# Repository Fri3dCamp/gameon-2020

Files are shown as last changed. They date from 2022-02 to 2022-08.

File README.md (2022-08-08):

# Fri3d GameOn 2020

This repository contains the hardware design of the [Fri3d Camp](https://fri3d.be/) GameOn that connects to the [badge](https://github.com/Fri3dCamp/badge-2020).
The board consists our of a joystick, some buttons, a Micro SD card slot and a small 1W audio amplifier.
The project progress can be followed on our [Hackaday.io](https://hackaday.io/project/183766-gameon) page.

## Blockdiagram

In order to make the documentation easier to use, we've added the block diagram in this repository.

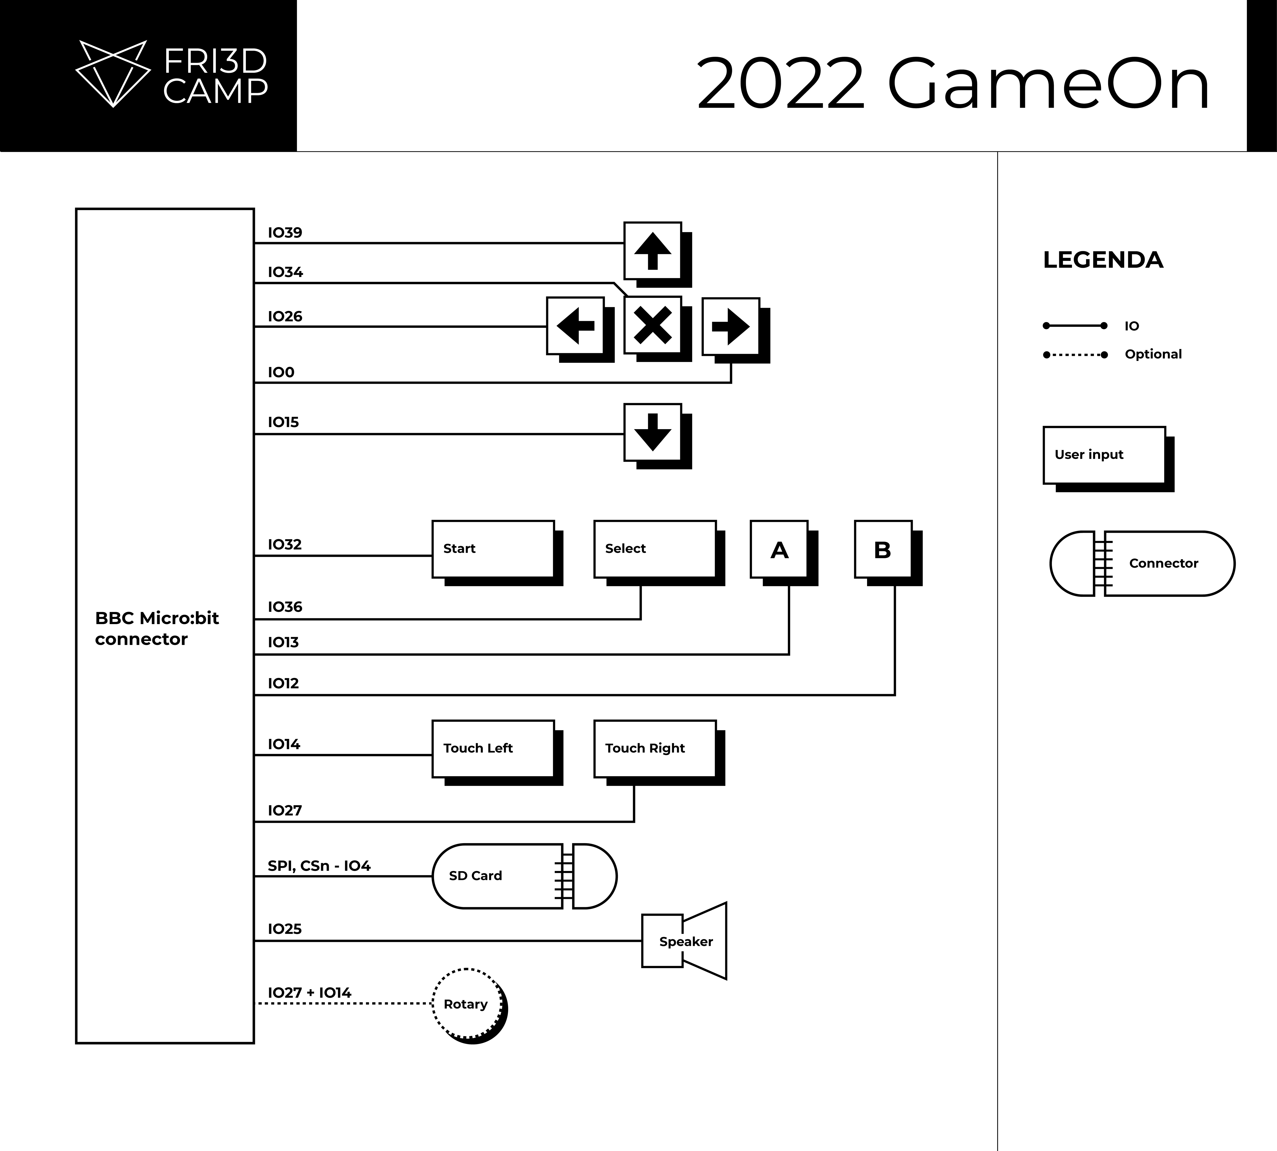
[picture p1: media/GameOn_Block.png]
GameOn Block Diagram


## REV 00
First prototype to verify the schematic design.

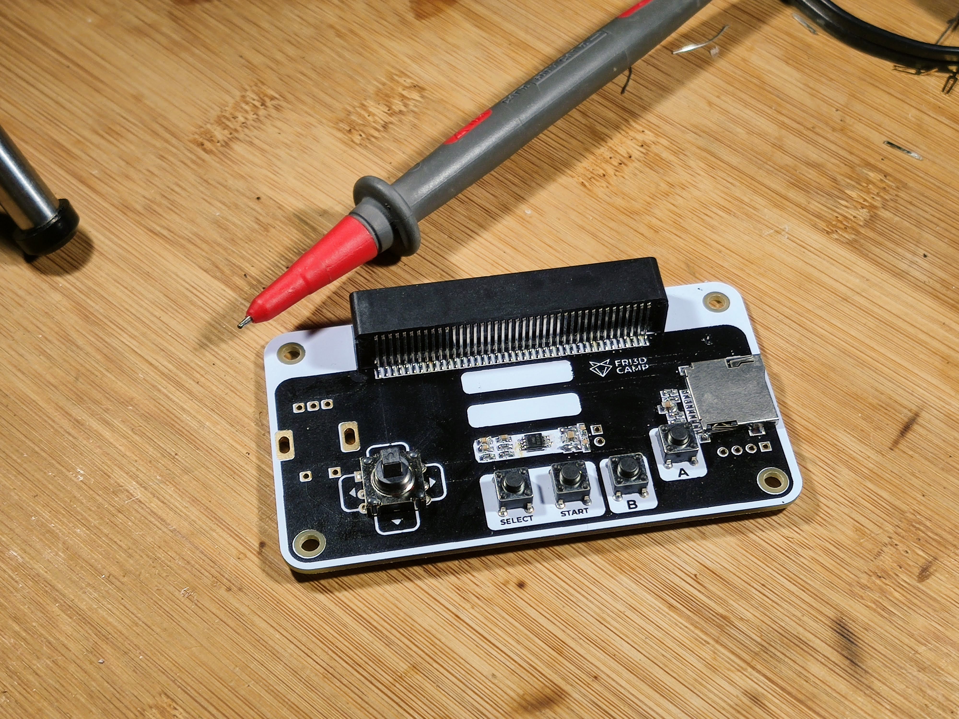
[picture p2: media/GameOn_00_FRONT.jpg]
GameOn Front 00


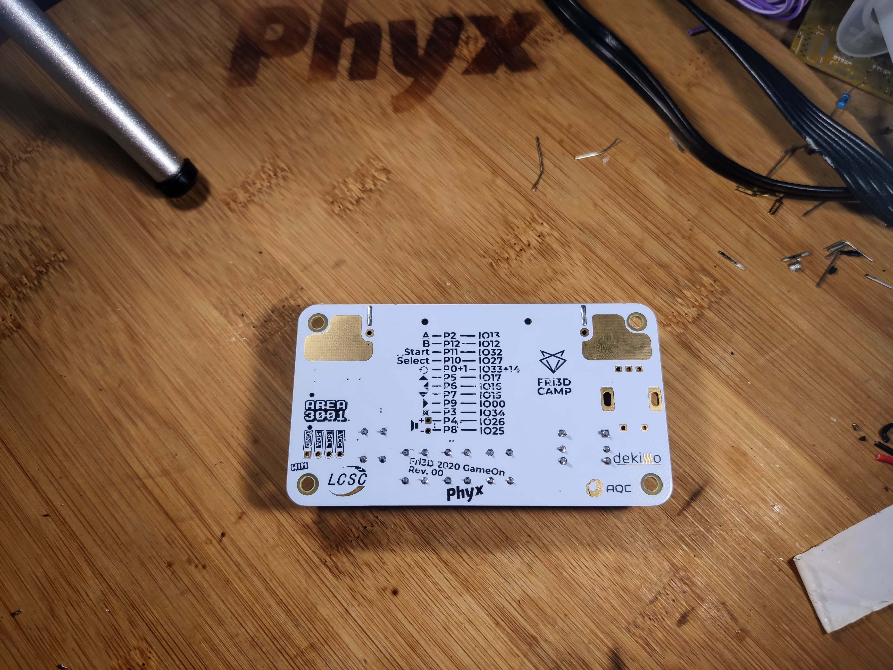
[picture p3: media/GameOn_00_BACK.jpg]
GameOn Back 00


## REV 01
Modified the pinout for the new hardware revision of the badge.

## REV 02
Production version of the GameOn. 

Note that the Start button, connected to the [badge](https://github.com/Fri3dCamp/badge-2020) IO pin 32, is active high whilst all other buttons are active low.

## 3D Printed Joystick
[Mathy Vanvoorden](https://github.com/MathyV)) designed a small joystick to click on the directional switch. Thereby making the directional switch easier to use. You can find the 3D model in the mechanical folder.

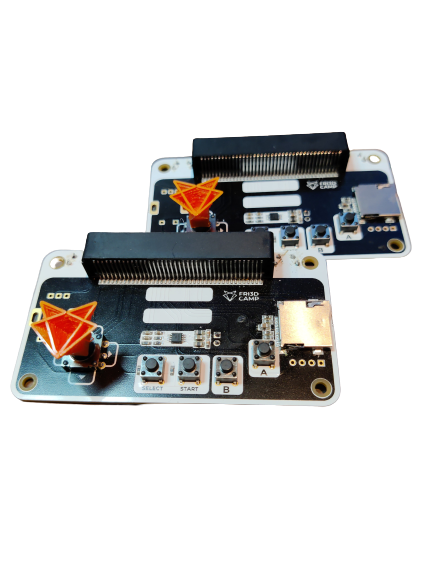
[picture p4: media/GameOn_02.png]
GameOn 02


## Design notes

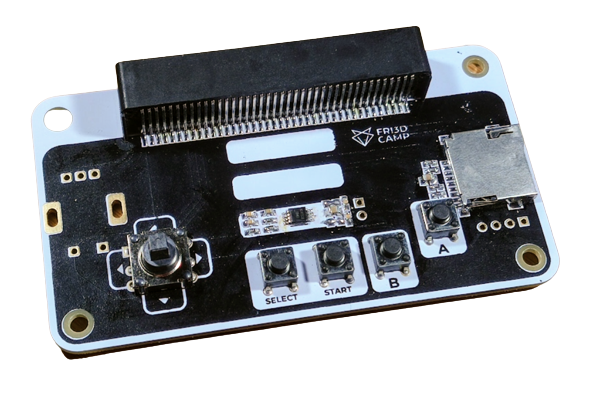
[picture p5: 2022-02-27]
media/GameOn_00_noBG.png

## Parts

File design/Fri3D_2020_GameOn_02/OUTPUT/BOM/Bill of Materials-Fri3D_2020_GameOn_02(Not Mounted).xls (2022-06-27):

Bill of Materials |  |  | Fri3D 2022 GameOn
Project: |  | Fri3D_2020_GameOn_02.PrjPcb
Revision: |  | 02
Variant: |  | Not Mounted
Creation Date: | 06/06/2022 | 20:51
Print Date: | 2022-06-06 | 20:51:31
Footprint | Comment | LibRef | Designator | Value | Description | Supplier 1 | Supplier Part Number 1 | Supplier 2 | Supplier Part Number 2 | Supplier 3 | Supplier Part Number 3 | Quantity
C0603_N |  | CAP # 100nF 50V 0603 | C1, C2 | 100nF 50V | CAP # 100nF 50V 0603 | Farnell | 1759122 | LCSC | C282519 | Generic | 100nF 50V 0603 X7R | 2
C0603_N |  | CAP # 1nF 16V 0603 | C3, C4 | 1nF 16V | CAP # 1nF 16V 0603 |  |  |  |  | Generic | 1nF 16V 0603 X7R | 2
C0805_N |  | CAP # 10uF 10V 0805 | C5, C6 | 10uF 10V | CAP # 10uF 10V 0805 | Farnell | 2320859 | LCSC | C17024 | Generic | 10uF 10V 0805 X7R | 2
C0603_N |  | CAP # 1uF 50V 0603 | C7 | 1uF 50V | CAP # 1uF 50V 0603 | Farnell | 2112858 |  |  | Generic | 1uF 50V 0603 X7R | 1
L0805 |  | FER # 600R 2A 0805 0R10 | F1, F2 | 2A 0R1 | FER # 600R 2A 0805 0R10 | Farnell | 1838838 |  |  |  |  | 2
TFP09-2-12B | Micro SD PiPo Push-Push | MicroSD TFP09-2-12B Push-Push | J1 | TFP09-2-12B | MicroSD TFP09-2-12B Push-Push | AliExpress | TFP09-2-12B | LCSC | C393941 | LCSC | C381082 | 1
MicroBIT_CYLCONN_SMD_180 | MicroBit 180deg connector Cylconn | MicroBit # Cylconn | P2 |  | MicroBit # Cylconn | TaoBao |  |  |  |  |  | 1
R0603_N |  | RES # 10K 0603 | R1, R2, R3, R4, R5, R6, R7, R8, R9 | 10K | RES # 10K 0603 | Farnell | 2502397 | LCSC | C25804 | Generic | 10K 1% 0603 | 9
TACTSW | Default TH TACT | SW TACT | SW1, SW2, SW3, SW4 |  | SW TACT | LCSC | C393938 |  |  |  |  | 4
TACTSW_5W_K1-1506DN-01 | 5Way Tact switch | SW TACT 5W K1-1506DN-01 | SW5 | K1-1506DN-01 | SW TACT 5W K1-1506DN-01 | LCSC | C145911 |  |  |  |  | 1
TACTSW_RA_385 | Tact switch, RA, 3,85mm | SW TACT RA 3,85mm 431256038716 | SW6, SW7 | 431256038716 | SW TACT RA 3,85mm 431256038716 | Wurth | 431256038716 | Mouser | 710-431256038716 |  |  | 2
MAX_uSOP8 | 5W Class D mono amplifier inducter-less Differential input MSOP8 | AMP # AUDIO NS4150B | U1 | NS4150B | AMP # AUDIO NS4150B | LCSC | C189961 |  |  |  |  | 1
 |  |  |  |  |  |  |  |  |  |  |  | 28
Approved |  | Notes

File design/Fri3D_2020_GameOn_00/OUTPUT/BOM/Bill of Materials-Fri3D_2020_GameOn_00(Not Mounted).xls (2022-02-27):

Bill of Materials |  |  | Fri3D 2020 GameOn
Project: |  | Fri3D_2020_GameOn_00.PrjPcb
Revision: |  | 00
Variant: |  | Not Mounted
Creation Date: | 25/03/2020 | 19:29
Print Date: | 2020-03-25 | 19:44:46
Footprint | Comment | LibRef | Designator | Value | Description | Supplier 1 | Supplier PN 1 | Supplier 2 | Supplier PN 2 | Supplier 3 | Supplier PN 3 | Quantity
C0603_N |  | CAP # 100nF 50V 0603 | C1, C2 | 100nF 50V | CAP # 100nF 50V 0603 | LCSC | C83054 | Farnell | 1759122 | Generic | 100nF 50V 0603 X7R | 2
C0603_N |  | CAP # 1nF 16V 0603 | C3, C4 | 1nF 16V | CAP # 1nF 16V 0603 | LCSC | C99917 |  |  | Generic | 1nF 16V 0603 X7R | 2
C0805_N |  | CAP # 10uF 10V 0805 | C5, C6 | 10uF 10V | CAP # 10uF 10V 0805 | LCSC | C1713 | Farnell | 2320859 | Generic | 10uF 10V 0805 X7R | 2
C0603_N |  | CAP # 1uF 50V 0603 | C7 | 1uF 50V | CAP # 1uF 50V 0603 | LCSC | C1592 | Farnell | 2112858 | Generic | 1uF 50V 0603 X7R | 1
L0805 |  | FER # 600R 2A 0805 0R10 | F1, F2 | 2A 0R1 | FER # 600R 2A 0805 0R10 | LCSC | C21286 | Farnell | 1838838 |  |  | 2
TFP09-2-12B | Micro SD PiPo Push-Push | MicroSD TFP09-2-12B Push-Push | J1 | TFP09-2-12B | MicroSD TFP09-2-12B Push-Push | LCSC | C393941 |  |  |  |  | 1
MicroBIT_CYLCONN_SMD_90 | MicroBit 90deg connector Cylconn | MicroBit # RA Cylconn | P1 |  | MicroBit # RA Cylconn | TaoBao |  |  |  |  |  | 1
R0603_N |  | RES # 10K 0603 | R1, R2, R3, R4, R5, R6, R7 | 10K | RES # 10K 0603 | LCSC | C115324 | Farnell | 2502397 | Generic | 10K 1% 0603 | 7
TACTSW | Default TH TACT | SW TACT | SW1, SW2, SW3, SW4 |  | SW TACT | LCSC | C393938 |  |  |  |  | 4
TACTSW_5W_K1-1506DN-01 | 5Way Tact switch | SW TACT 5W K1-1506DN-01 | SW5 | K1-1506DN-01 | SW TACT 5W K1-1506DN-01 | LCSC | C145911 |  |  |  |  | 1
 |  | SPK 8R 1W 23mm | SPEAKER | 23M02-8T-H43 | SPK 8R 1W 23mm | LCSC | C391013 |  |  |  |  | 1
MAX_uSOP8 | 5W Class D mono amplifier inducter-less Differential input MSOP8 | AMP # AUDIO NS4150B | U1 | NS4150B | AMP # AUDIO NS4150B | LCSC | C189961 |  |  |  |  | 1
 |  |  |  |  |  |  |  |  |  |  |  | 25
Approved |  | Notes

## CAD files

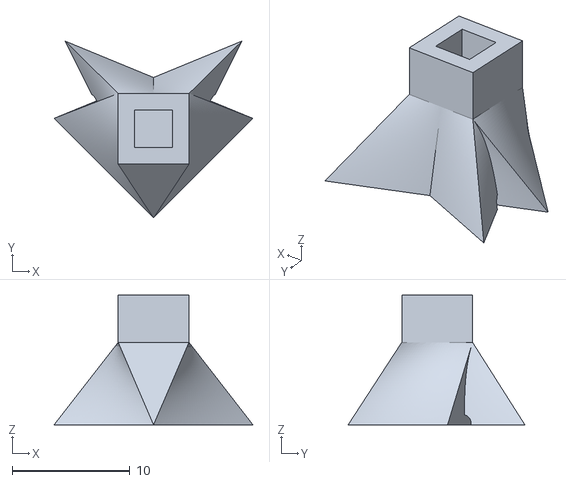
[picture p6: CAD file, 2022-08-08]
mechanical/JoyButton_v3.stl
16.9 x 15.0 x 11.0

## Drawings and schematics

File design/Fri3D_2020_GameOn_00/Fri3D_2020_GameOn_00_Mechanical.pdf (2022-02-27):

## Fri3D 2020 GameOn Mechanical drawings

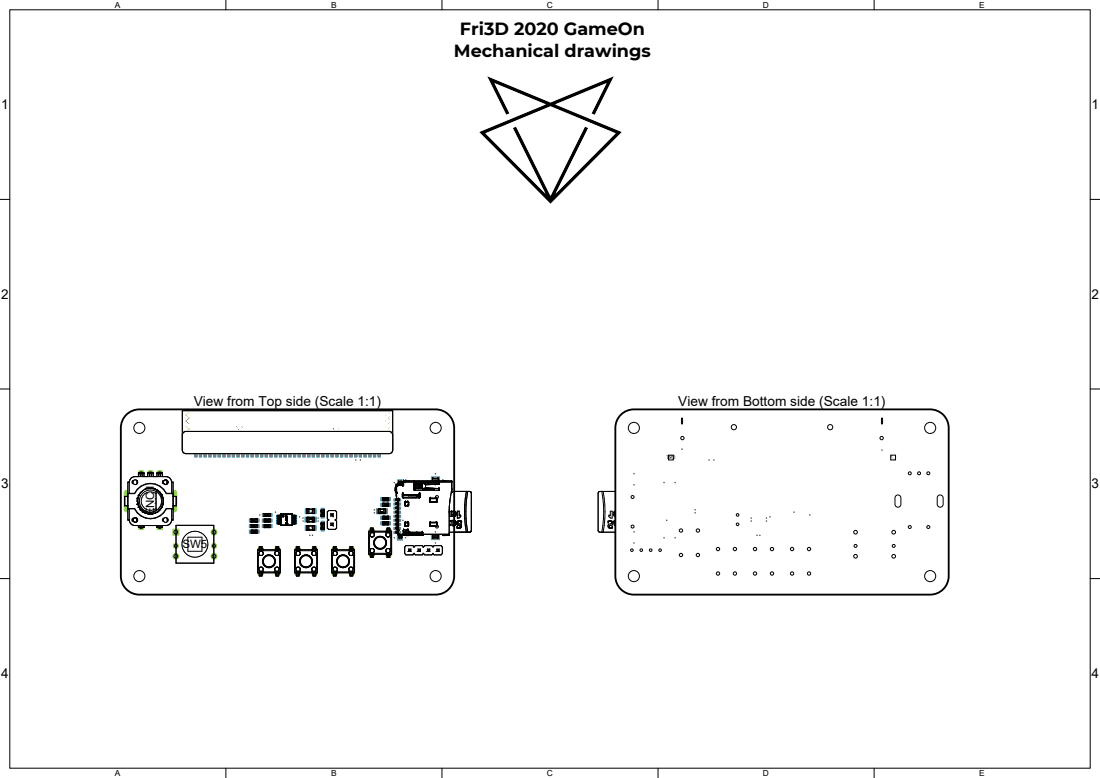
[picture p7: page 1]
4 ENC¹; ENC1

View from Top side (Scale 1:1)

View from Bottom side (Scale 1:1)

## Fri3D 2020 GameOn Silkscreen

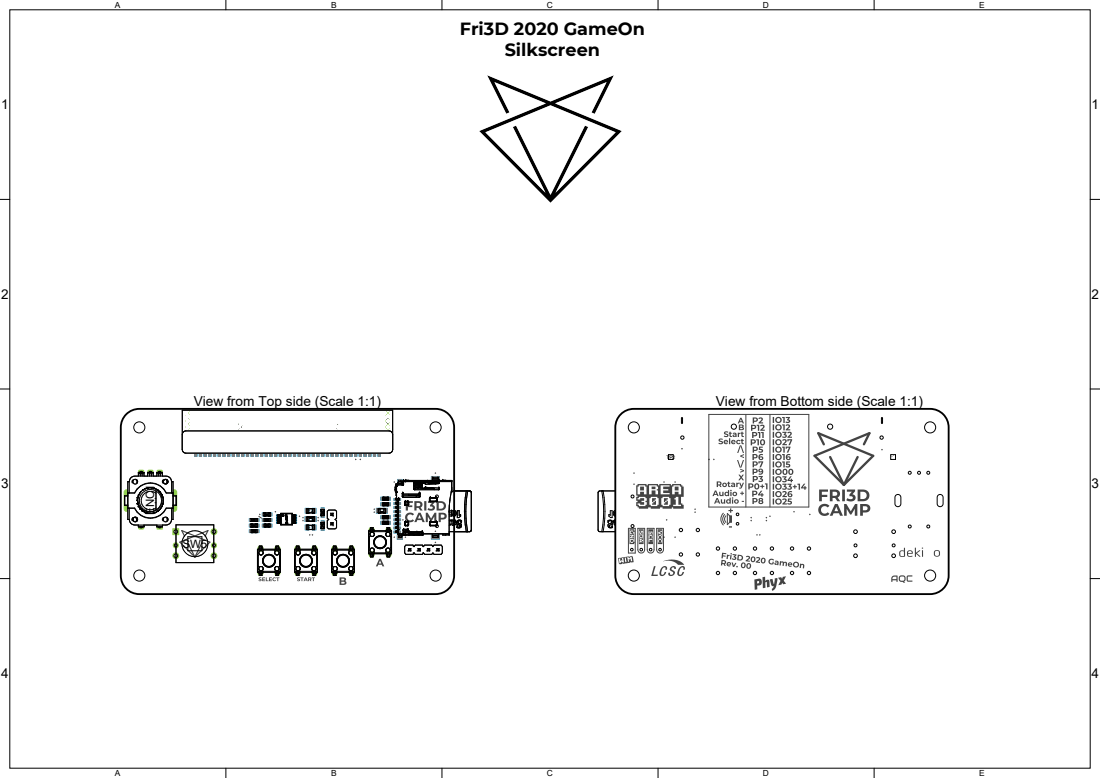
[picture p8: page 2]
ENC1

View from Top side (Scale 1:1)

View from Bottom side (Scale 1:1)

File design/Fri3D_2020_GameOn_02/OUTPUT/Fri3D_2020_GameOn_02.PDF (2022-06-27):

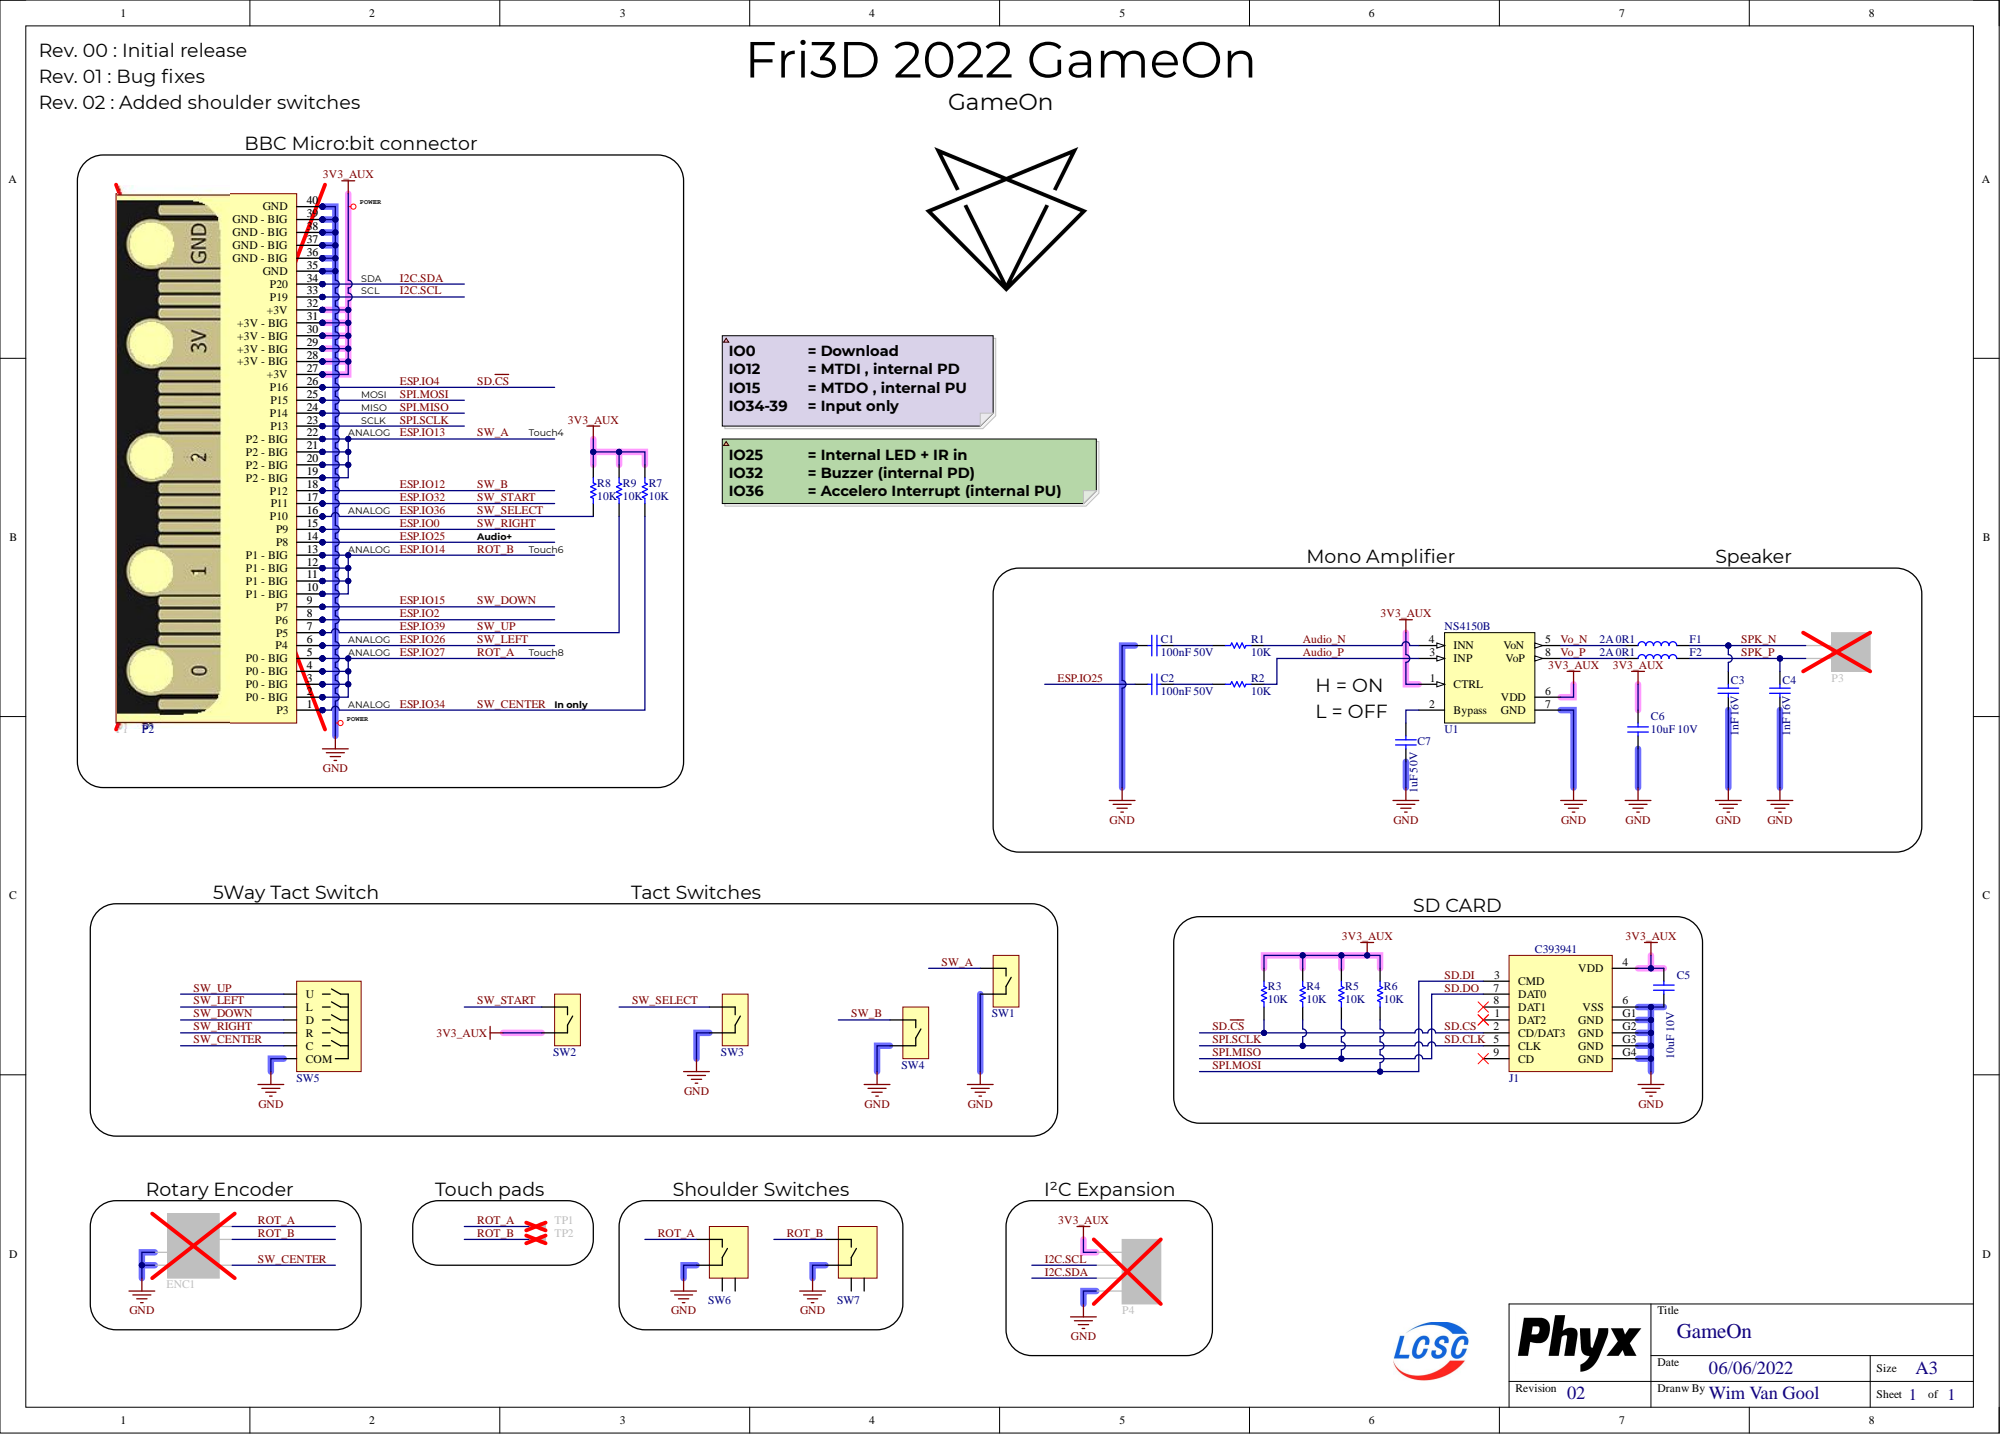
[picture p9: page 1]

Rev. 00 : Initial release
Rev. 01 : Bug fixes
Rev. 02 : Added shoulder switches

BBC Micro:bit connector

SD.CS SD.CLK | DAT1 8

Rev. 00 : Initial release
Rev. 01 : Bug fixes
Rev. 02 : Added shoulder switches

BBC Micro:bit connector

SD.CS SD.CLK | DAT1 8

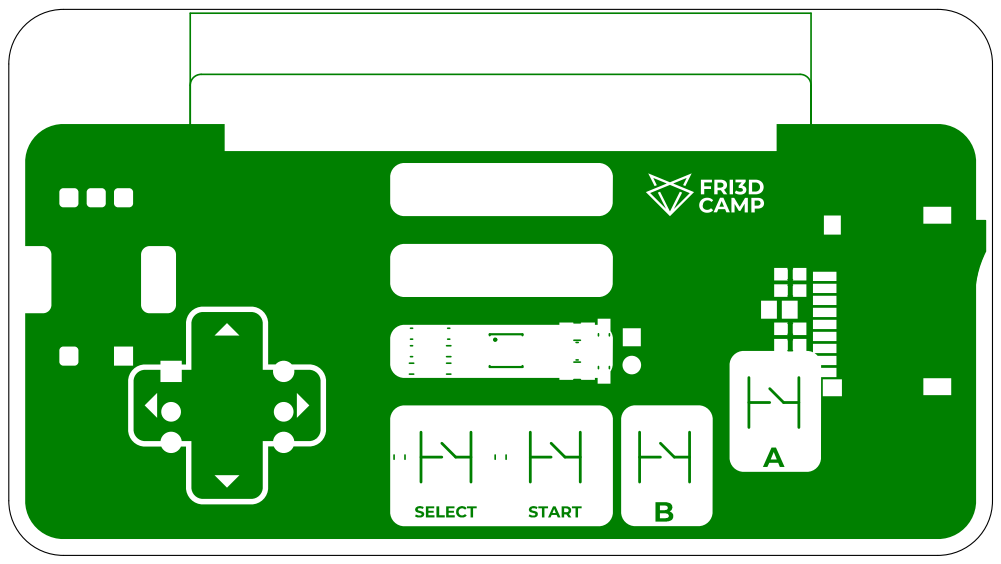
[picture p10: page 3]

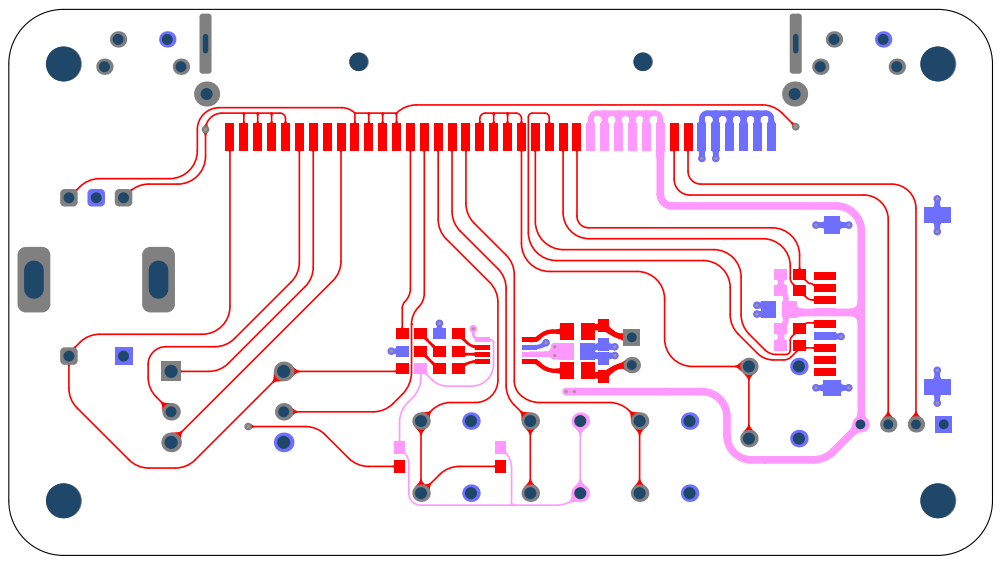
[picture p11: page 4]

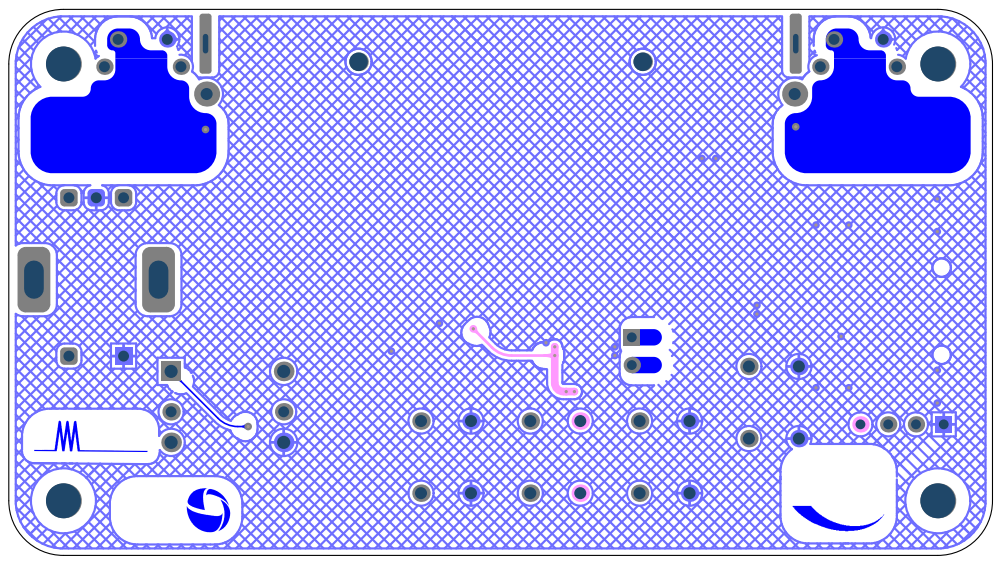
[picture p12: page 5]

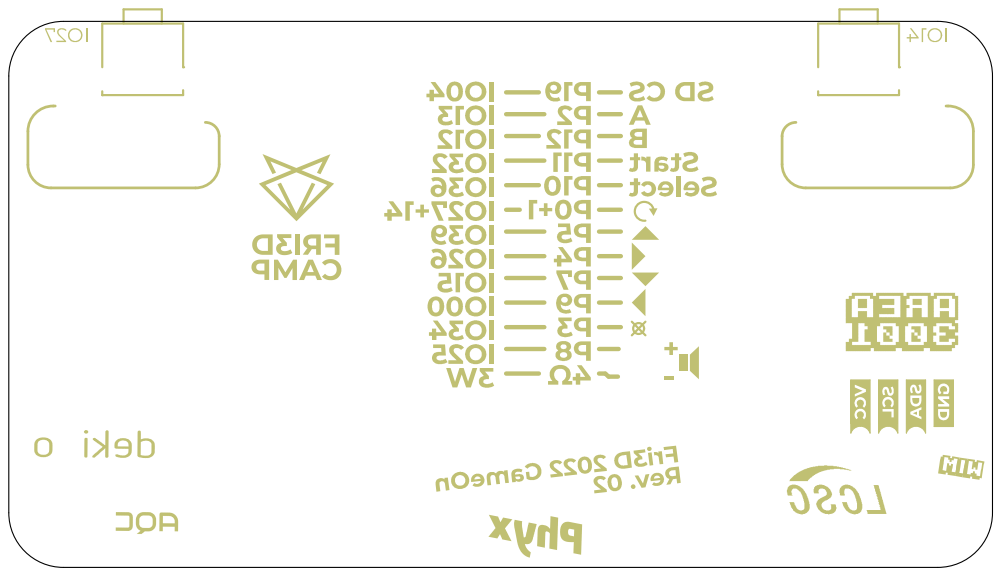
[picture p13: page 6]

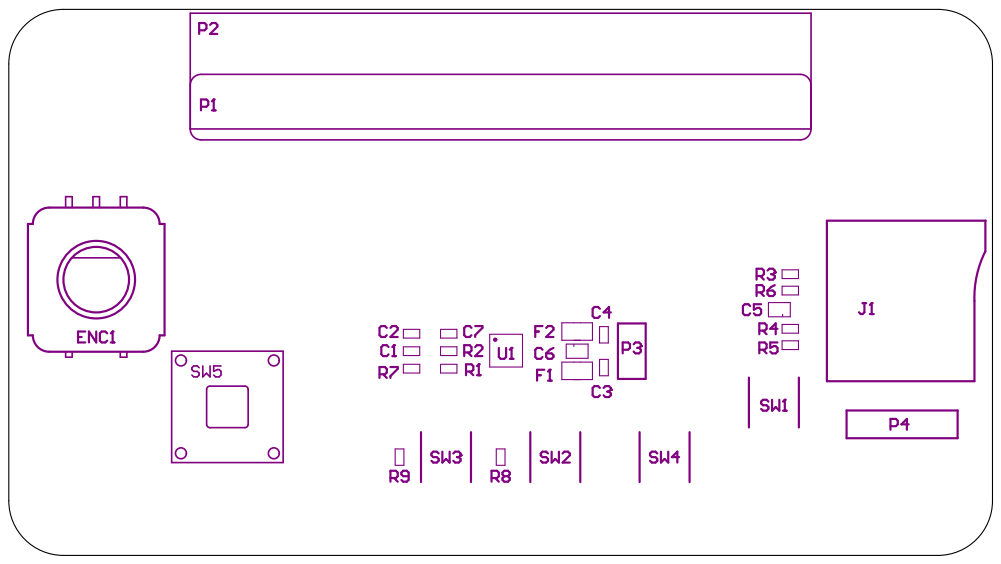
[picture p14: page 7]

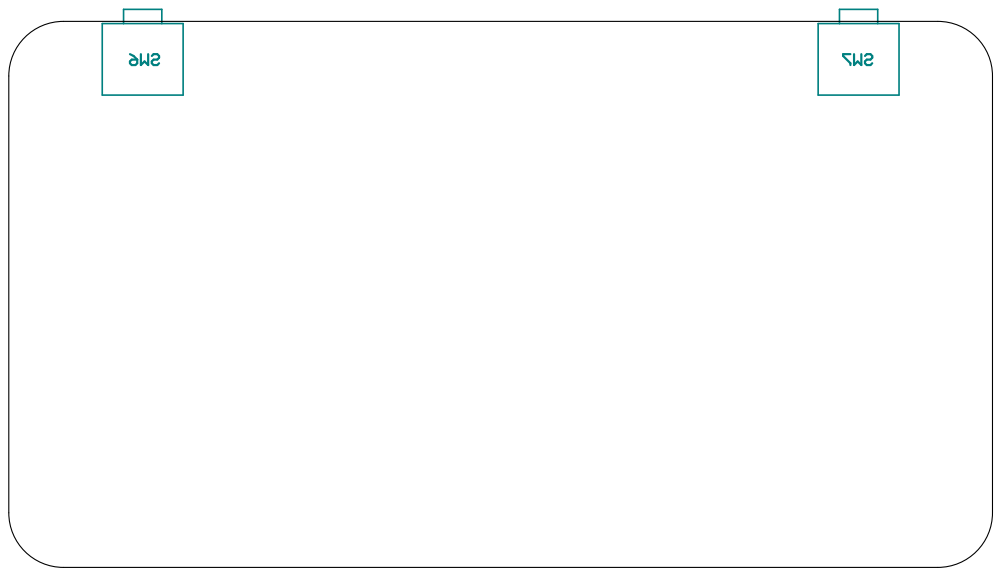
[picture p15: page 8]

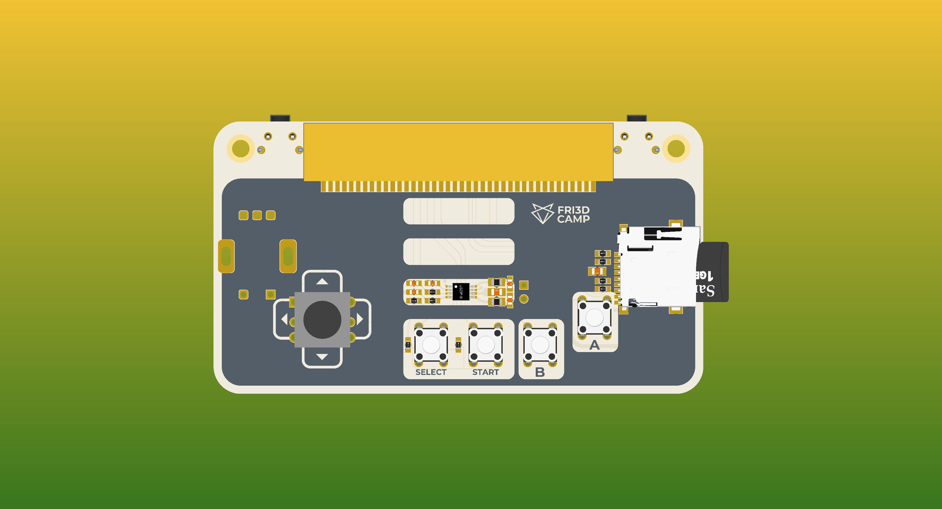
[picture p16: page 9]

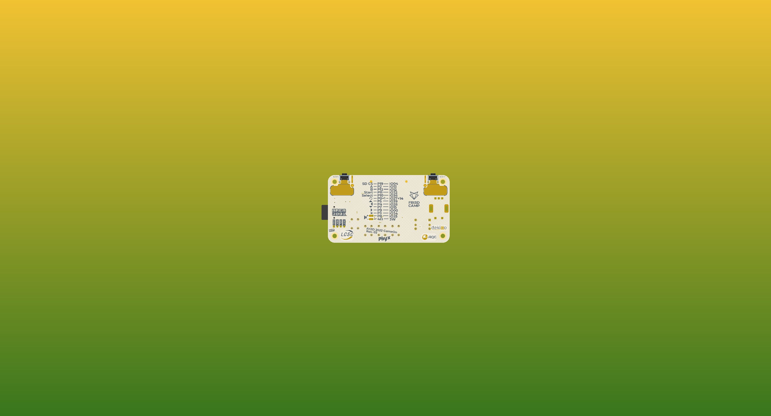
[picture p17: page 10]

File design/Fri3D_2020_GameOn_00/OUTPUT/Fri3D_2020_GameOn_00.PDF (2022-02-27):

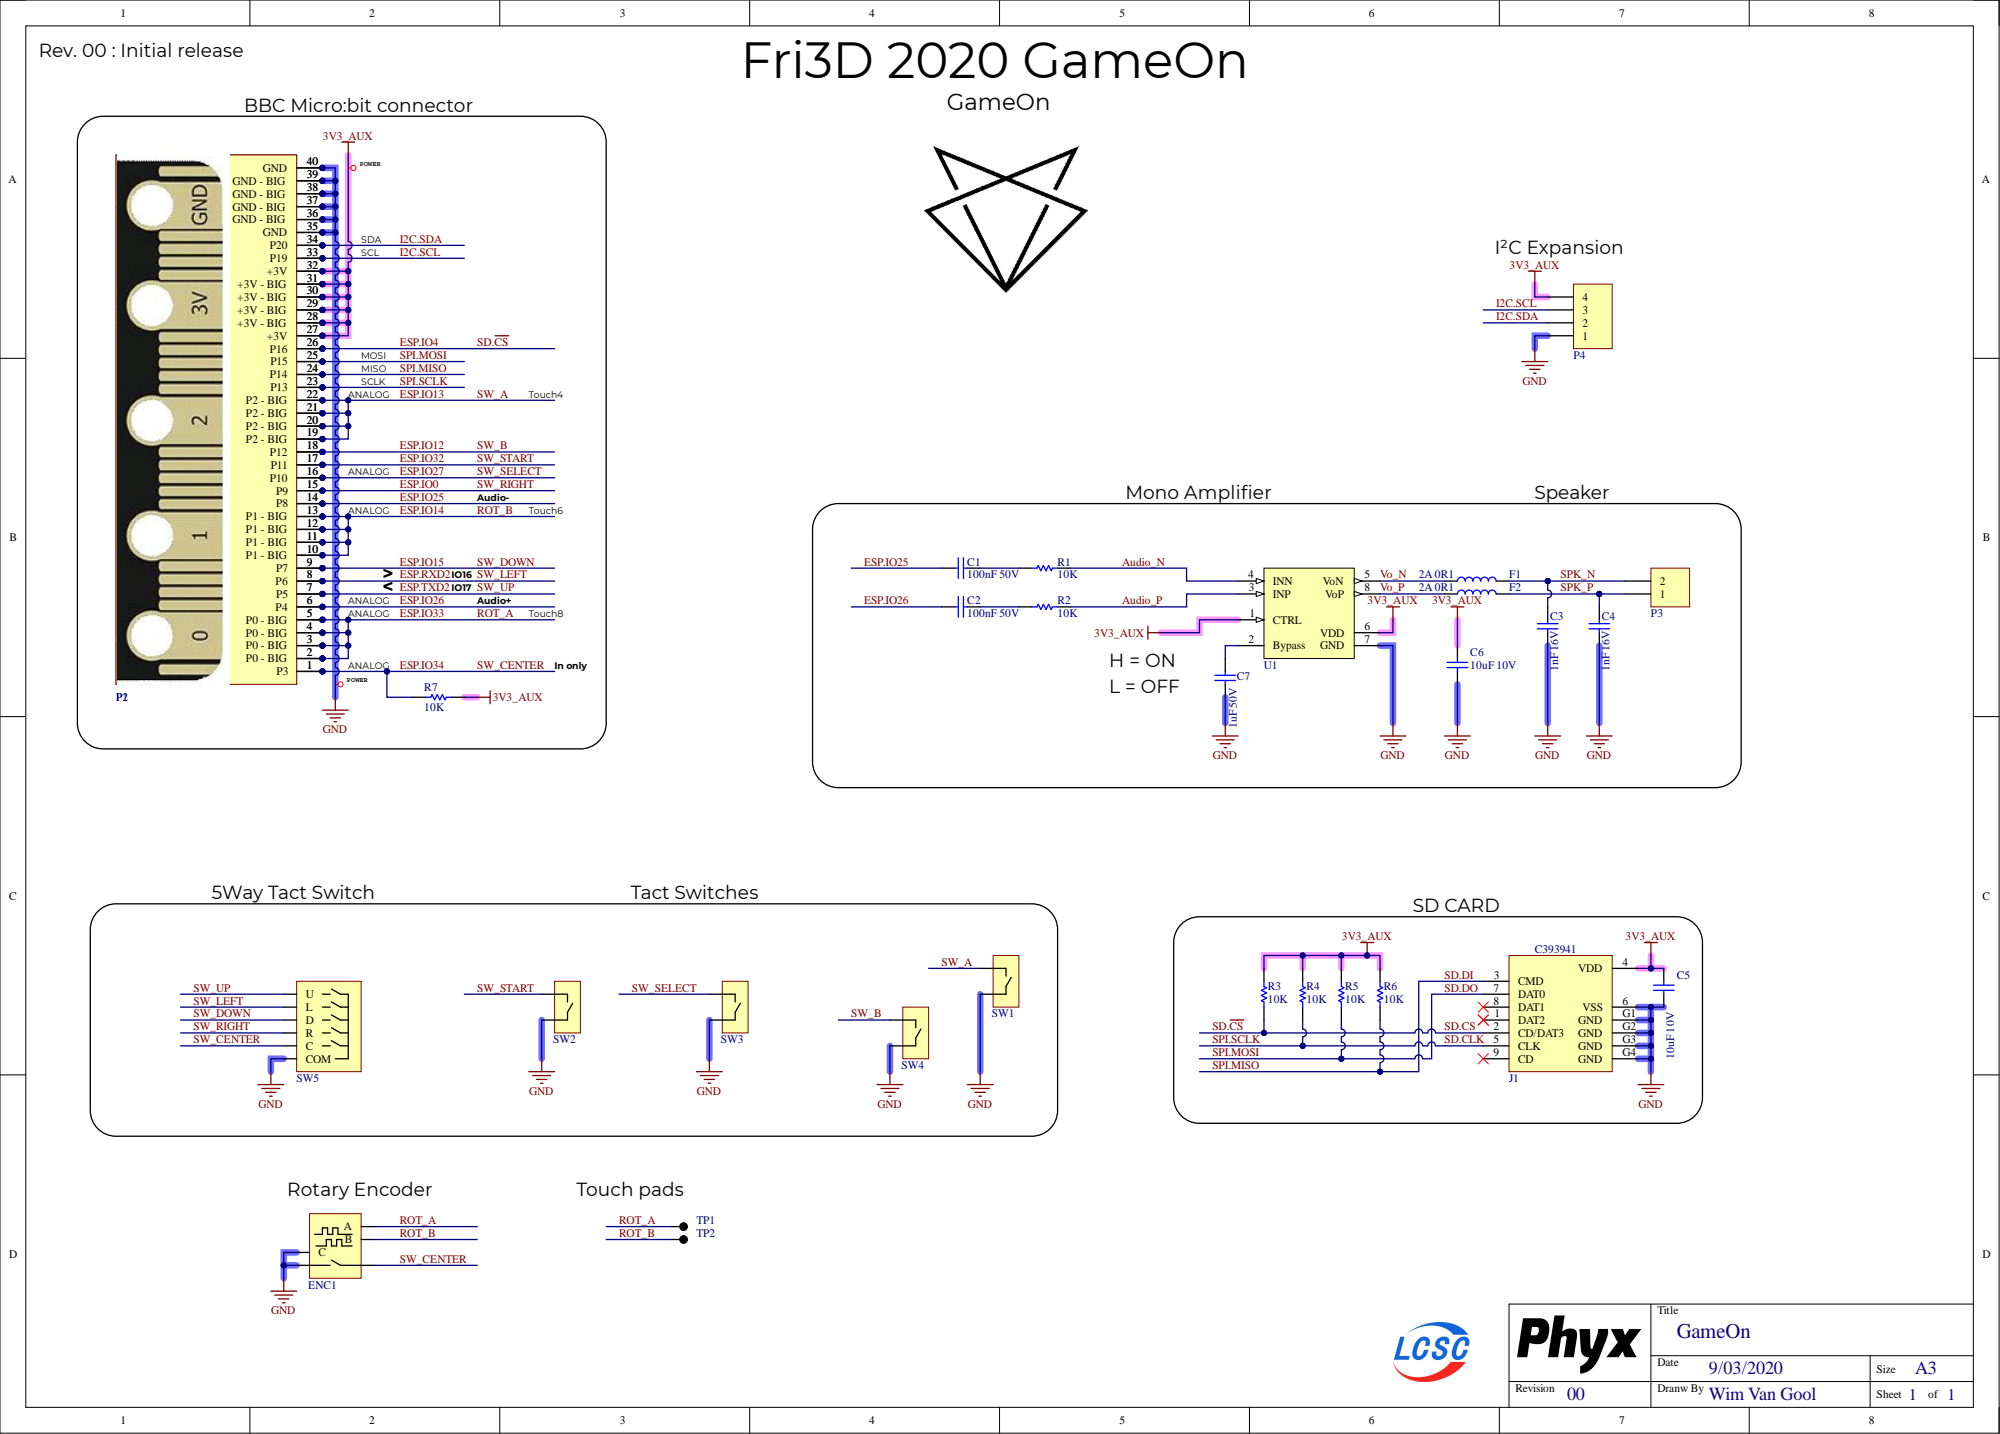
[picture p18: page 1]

BBC Micro:bit connector

SD.CS SD.CLK | DAT1 8


BBC Micro:bit connector

SD.CS SD.CLK | DAT1 8









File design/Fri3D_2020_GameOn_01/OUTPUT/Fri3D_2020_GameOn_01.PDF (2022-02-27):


BBC Micro:bit connector

ESP.IO12 SW_B
ESP.IO32 SW_START

ESP.IO0 SW_RIGHT
Audio+ ESP.IO25

SD.CS SD.CLK | DAT1 8

BBC Micro:bit connector

ESP.IO12 SW_B
ESP.IO32 SW_START

ESP.IO0 SW_RIGHT
Audio+ ESP.IO25

SD.CS SD.CLK | DAT1 8









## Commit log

2022-02-27 Rev. 00 and 01
    Added revision 00 and 01 design files and basic documentation
    [Bill of Materials-Fri3D_2020_GameOn_00(Not Mounted).xls, Bill of Materials-Fri3D_2020_GameOn_01(Not Mounted).xls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]
2022-06-27 Rev.02 added
    Added Revision 02 design and production files
    [Bill of Materials-Fri3D_2020_GameOn_02(Not Mounted).xls, Fri3D_2020_GameOn_02.PrjPcb, Fri3D_2020_GameOn_02.SchDoc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]
2022-08-08 added 3D print by MathyV
    [JoyButton_v3.stl]
